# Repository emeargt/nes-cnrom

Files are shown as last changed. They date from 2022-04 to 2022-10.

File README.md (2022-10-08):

# nes-cnrom
[][cc-by-sa]

[cc-by-sa]: http://creativecommons.org/licenses/by-sa/4.0/
[cc-by-sa-shield]: https://img.shields.io/badge/License-CC%20BY--SA%204.0-lightgrey.svg

This repository contains a KiCad project for a NES-CN-ROM-256-05 cartridge pcb.

Original NES-CN-ROM-256-05 schematic is from N. Schenk's [NES repo](https://github.com/schenkzoola/NES/tree/main/Cartridges/NES/NES-CN-ROM-256-05). The schematic was modified to include currently available parts and their associated footprints.

The board matches the dimensions of the original and will idealy fit in standard or reproduction shells. A list of parts to populate the board can be found in the bom directory.

## Build Guide
There is a basic [build guide](./docs/buildguide.md) that provides some tips and resources for bringing up a board.

## Memory Support
v02 was designed to support the SST39SF0x0A series of 32 DIP flash chips. However, the AT27CxxxR series of 28 DIP EPROMs have a very similar pinout and should work on the board by mapping pin 1 of the EPROM to pin 3 of the 32 DIP footprint. Other 28 DIP memory chips may work as well, but their pinouts should be compared to that of the SST39SF0x0A to be certain.

## Schematic


## Board Layout
Top | Bottom
:---: | :---:
 | 

Board render (front):
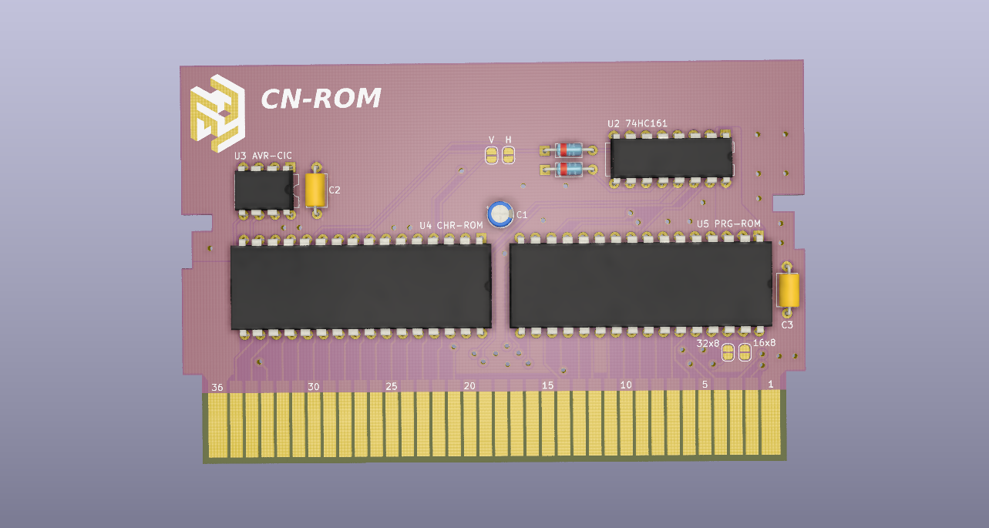
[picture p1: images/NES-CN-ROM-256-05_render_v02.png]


## Changelog

### [v02]
- New board layout to support 32 DIP flash chips (SST39SF0x0A)
- Add isometric logo design
- Increase board dimensions

### [v01.1]
- Connected pins 57 and 58 on the cartridge edge connector for internal VRAM enable.

### [v01]
- Initial schematic and board layout.

[v02]: https://github.com/emeargt/nes-cnrom/releases/tag/v02
[v01.1]: https://github.com/emeargt/nes-cnrom/releases/tag/v01.1
[v01]: https://github.com/emeargt/nes-cnrom/releases/tag/v01-alpha

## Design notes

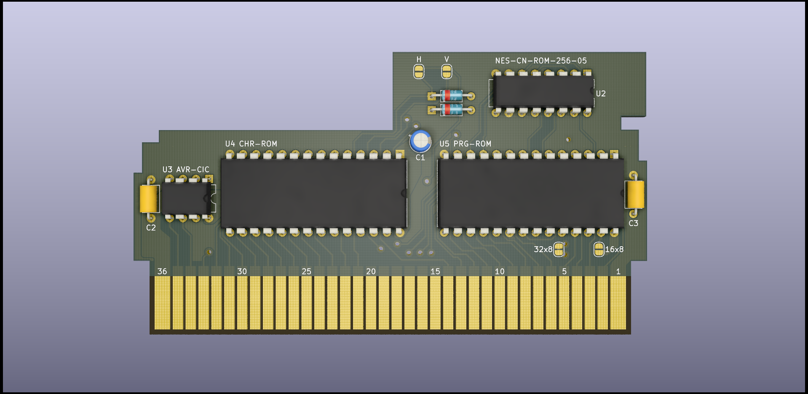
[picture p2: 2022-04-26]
images/NES-CN-ROM-256-05_render_v01.png

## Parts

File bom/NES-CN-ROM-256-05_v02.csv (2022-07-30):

Reference | Quantity | Value | Footprint | Notes | Datasheet
C1 | 1 | 22uF | Capacitor_THT:CP_Radial_D4.0mm_P1.50mm |  | https://www.digikey.ca/en/products/detail/panasonic-electronic-components/EEA-GA1A220/2504565
C2 C3 | 2 | 10nF | Capacitor_THT:C_Axial_L5.1mm_D3.1mm_P7.50mm_Horizontal |  | https://www.digikey.ca/en/products/detail/kemet/C410C103K5R5TA7200/818228
D1 D2 | 2 | 1N4148 | Diode_THT:D_DO-35_SOD27_P7.62mm_Horizontal | Do not populate (don't need to buy) | https://www.digikey.ca/en/products/detail/onsemi/1N4148TR/458811
U2 | 1 | 74HC161 | Package_DIP:DIP-16_W7.62mm |  | https://www.digikey.ca/en/products/detail/texas-instruments/SN74HC161N/376952
U3 | 1 | ATtiny13A-PU | Package_DIP:DIP-8_W7.62mm |  | https://www.digikey.ca/en/products/detail/microchip-technology/ATTINY13A-PU/1914671
U4 | 1 | CHR-ROM | Package_DIP:DIP-32_W15.24mm | Any SST39SF0x0A supported | https://www.digikey.ca/en/products/detail/microchip-technology/SST39SF010A-70-4C-PHE/2297826
U5 | 1 | PRG-ROM | Package_DIP:DIP-32_W15.24mm | Any SST39SF0x0A supported | https://www.digikey.ca/en/products/detail/microchip-technology/SST39SF010A-70-4C-PHE/2297826

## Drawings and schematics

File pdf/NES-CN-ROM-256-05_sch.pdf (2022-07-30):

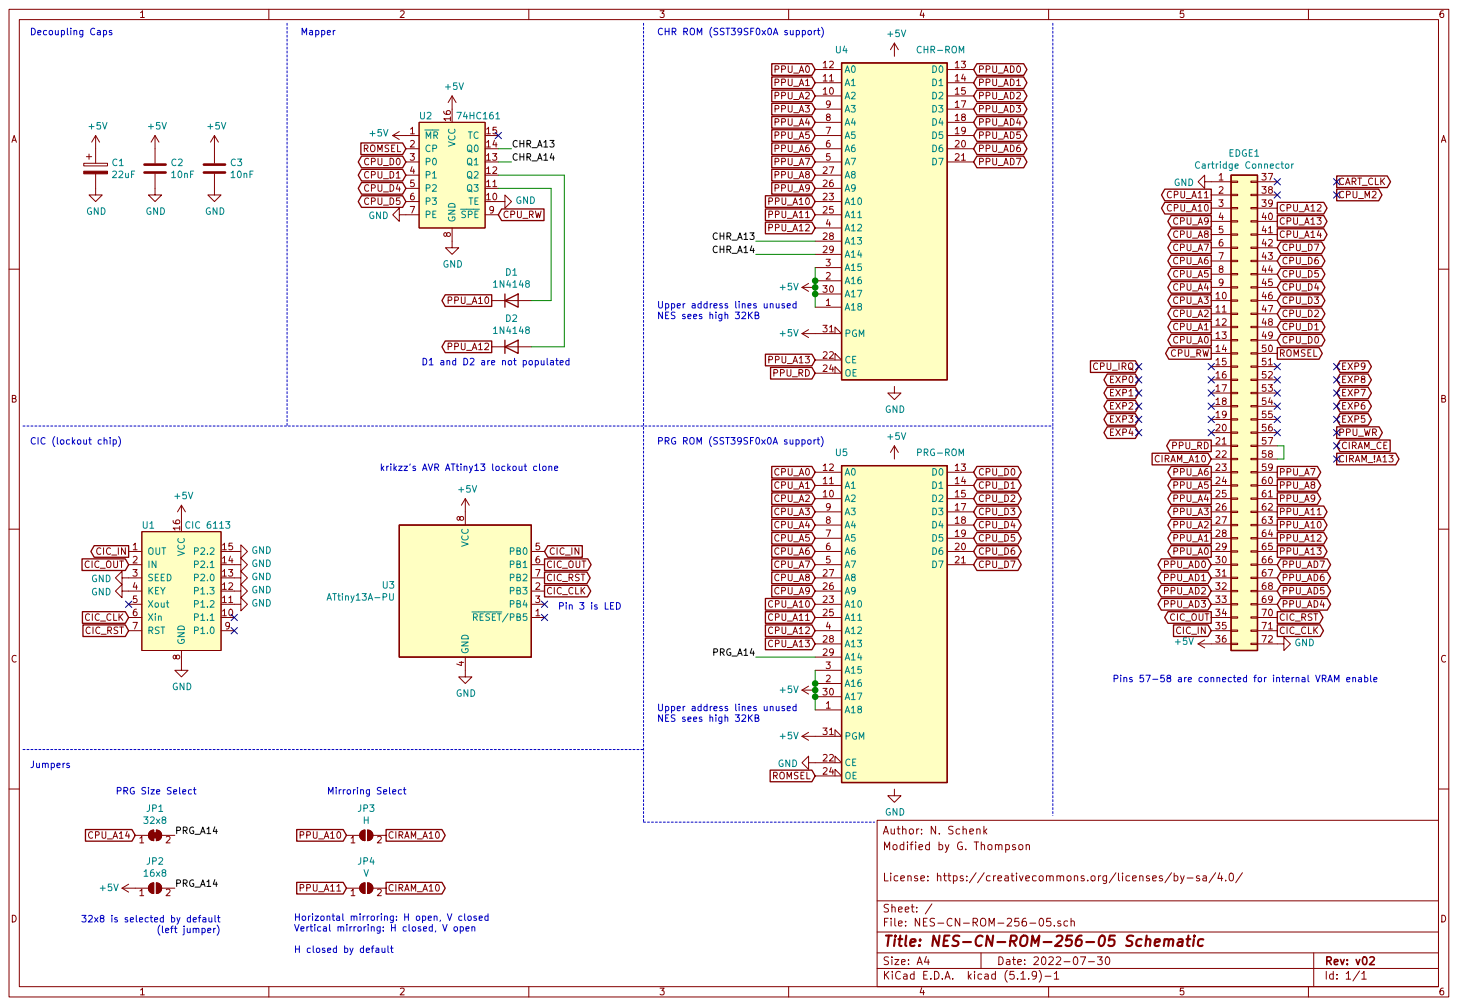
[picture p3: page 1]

8 P1.0 9 U1 CIC 6113 A18 1 A2 10 A1 11 A0 12 D0 13 D1 14 D2 15 D3 17 D4 18 D5 19 A16 2 D6 20 D7 21 CE 22 A10 23 OE 24 A11 25 A9 26 A8 27 A13 28 A14 29 A15 3 A17 30 PGM 31 A12 4 A7 5 A6 6 A5 7 A4 8 A3 9 U4 CHR-ROM

CHR_A13 Upper address lines unused

D1 and D2 are not populated

krikzz's AVR ATtiny13 lockout clone

Modified by G. Thompson Author: N. Schenk GND

Upper address lines unused
NES sees high 32KB

File: NES-CN-ROM-256-05.sch Sheet: / License: https://creativecommons.org/licenses/by-sa/4.0/

32x8 is selected by default

Horizontal mirroring: H open, V closed
Vertical mirroring: H closed, V open

Id: 1/1 Title: NES-CN-ROM-256-05 Schematic

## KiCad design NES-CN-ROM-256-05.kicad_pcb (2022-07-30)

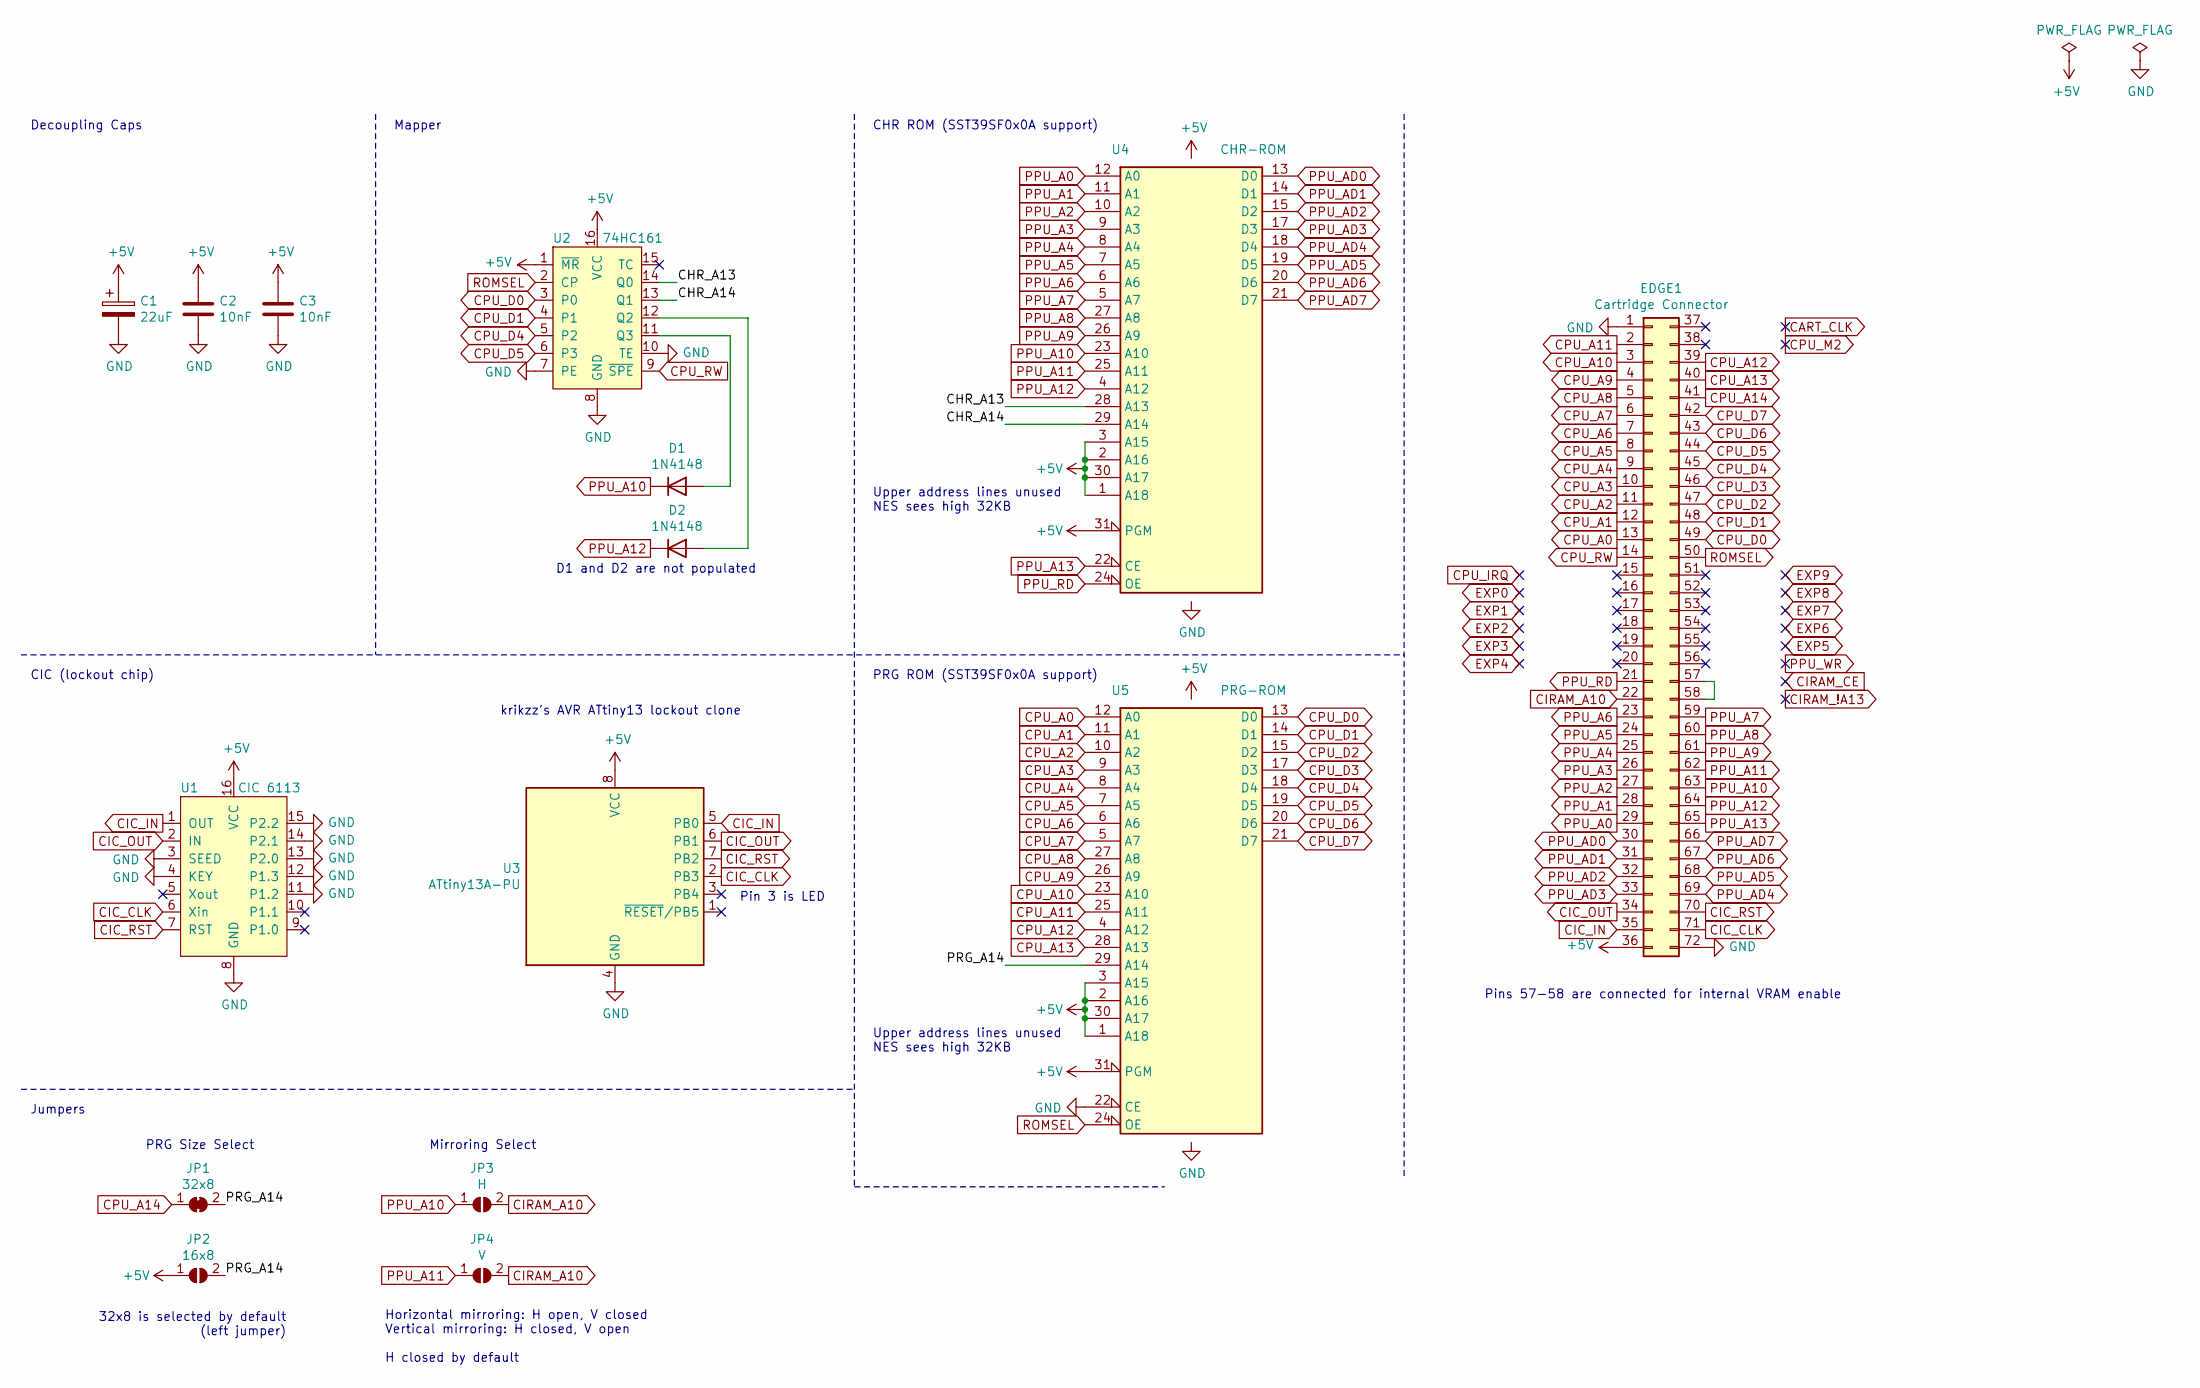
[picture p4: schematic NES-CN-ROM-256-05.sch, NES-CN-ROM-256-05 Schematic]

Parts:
C1: 22uF; CP_Radial_D4.0mm_P1.50mm
C2, C3: 10nF; C_Axial_L5.1mm_D3.1mm_P7.50mm_Horizontal
D1, D2: 1N4148; D_DO-35_SOD27_P7.62mm_Horizontal
EDGE1: Cartridge Connector; cartridge_edge_72
JP1: 32x8; SolderJumper-2_P1.3mm_Bridged_RoundedPad1.0x1.5mm
JP2: 16x8; SolderJumper-2_P1.3mm_Open_RoundedPad1.0x1.5mm
JP3: H; SolderJumper-2_P1.3mm_Open_RoundedPad1.0x1.5mm
JP4: V; SolderJumper-2_P1.3mm_Open_RoundedPad1.0x1.5mm
U1: CIC 6113; DIP-16_W7.62mm
U2: 74HC161; DIP-16_W7.62mm
U3: ATtiny13A-PU; DIP-8_W7.62mm
U4: CHR-ROM; DIP-32_W15.24mm
U5: PRG-ROM; DIP-32_W15.24mm

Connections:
+5V: C1.1, C2.1, C3.1, EDGE1.36, JP2.1 (A), U1.16 (VCC), U2.1 (~MR), U2.16 (VCC), U3.8 (VCC), U4.1 (A18), U4.2 (A16), U4.3 (A15), U4.30 (A17), U4.31 (PGM), U4.32 (VCC), U5.1 (A18), U5.2 (A16), U5.3 (A15), U5.30 (A17), U5.31 (PGM), U5.32 (VCC)
/CHR_A13: U2.14 (Q0), U4.28 (A13)
/CHR_A14: U2.13 (Q1), U4.29 (A14)
/PRG_A14: JP1.2 (B), JP2.2 (B), U5.29 (A14)
CIC_CLK: EDGE1.71, U1.6 (Xin), U3.2 (PB3)
CIC_IN: EDGE1.35, U1.1 (OUT), U3.5 (PB0)
CIC_OUT: EDGE1.34, U1.2 (IN), U3.6 (PB1)
CIC_RST: EDGE1.70, U1.7 (RST), U3.7 (PB2)
CIRAM_A10: EDGE1.22, JP3.2 (B), JP4.2 (B)
CPU_A0: EDGE1.13, U5.12 (A0)
CPU_A1: EDGE1.12, U5.11 (A1)
CPU_A2: EDGE1.11, U5.10 (A2)
CPU_A3: EDGE1.10, U5.9 (A3)
CPU_A4: EDGE1.9, U5.8 (A4)
CPU_A5: EDGE1.8, U5.7 (A5)
CPU_A6: EDGE1.7, U5.6 (A6)
CPU_A7: EDGE1.6, U5.5 (A7)
CPU_A8: EDGE1.5, U5.27 (A8)
CPU_A9: EDGE1.4, U5.26 (A9)
CPU_A10: EDGE1.3, U5.23 (A10)
CPU_A11: EDGE1.2, U5.25 (A11)
CPU_A12: EDGE1.39, U5.4 (A12)
CPU_A13: EDGE1.40, U5.28 (A13)
CPU_A14: EDGE1.41, JP1.1 (A)
CPU_D0: EDGE1.49, U2.3 (P0), U5.13 (D0)
CPU_D1: EDGE1.48, U2.4 (P1), U5.14 (D1)
CPU_D2: EDGE1.47, U5.15 (D2)
CPU_D3: EDGE1.46, U5.17 (D3)
CPU_D4: EDGE1.45, U2.5 (P2), U5.18 (D4)
CPU_D5: EDGE1.44, U2.6 (P3), U5.19 (D5)
CPU_D6: EDGE1.43, U5.20 (D6)
CPU_D7: EDGE1.42, U5.21 (D7)
CPU_RW: EDGE1.14, U2.9 (~SPE)
GND: C1.2, C2.2, C3.2, EDGE1.1, EDGE1.72, U1.3 (SEED), U1.4 (KEY), U1.8 (GND), U1.11 (P1.2), U1.12 (P1.3), U1.13 (P2.0), U1.14 (P2.1), U1.15 (P2.2), U2.7 (PE), U2.8 (GND), U2.10 (TE), U3.4 (GND), U4.16 (GND), U5.16 (GND), U5.22 (CE)
unnamed: D1.2 (A), U2.11 (Q3)
unnamed: D2.2 (A), U2.12 (Q2)
unnamed: EDGE1.57, EDGE1.58
PPU_A0: EDGE1.29, U4.12 (A0)
PPU_A1: EDGE1.28, U4.11 (A1)
PPU_A2: EDGE1.27, U4.10 (A2)
PPU_A3: EDGE1.26, U4.9 (A3)
PPU_A4: EDGE1.25, U4.8 (A4)
PPU_A5: EDGE1.24, U4.7 (A5)
PPU_A6: EDGE1.23, U4.6 (A6)
PPU_A7: EDGE1.59, U4.5 (A7)
PPU_A8: EDGE1.60, U4.27 (A8)
PPU_A9: EDGE1.61, U4.26 (A9)
PPU_A10: D1.1 (K), EDGE1.63, JP3.1 (A), U4.23 (A10)
PPU_A11: EDGE1.62, JP4.1 (A), U4.25 (A11)
PPU_A12: D2.1 (K), EDGE1.64, U4.4 (A12)
PPU_A13: EDGE1.65, U4.22 (CE)
PPU_AD0: EDGE1.30, U4.13 (D0)
PPU_AD1: EDGE1.31, U4.14 (D1)
PPU_AD2: EDGE1.32, U4.15 (D2)
PPU_AD3: EDGE1.33, U4.17 (D3)
PPU_AD4: EDGE1.69, U4.18 (D4)
PPU_AD5: EDGE1.68, U4.19 (D5)
PPU_AD6: EDGE1.67, U4.20 (D6)
PPU_AD7: EDGE1.66, U4.21 (D7)
PPU_RD: EDGE1.21, U4.24 (OE)
ROMSEL: EDGE1.50, U2.2 (CP), U5.24 (OE)

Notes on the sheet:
32x8 is selected by default (left jumper)
D1 and D2 are not populated
CHR ROM (SST39SF0x0A support)
PRG ROM (SST39SF0x0A support)
Mapper
Decoupling Caps
CIC (lockout chip)
Jumpers
krikzz's AVR ATtiny13 lockout clone
Mirroring Select
PRG Size Select
Pin 3 is LED
Horizontal mirroring: H open, V closed Vertical mirroring: H closed, V open H closed by default
Pins 57-58 are connected for internal VRAM enable
Upper address lines unused NES sees high 32KB

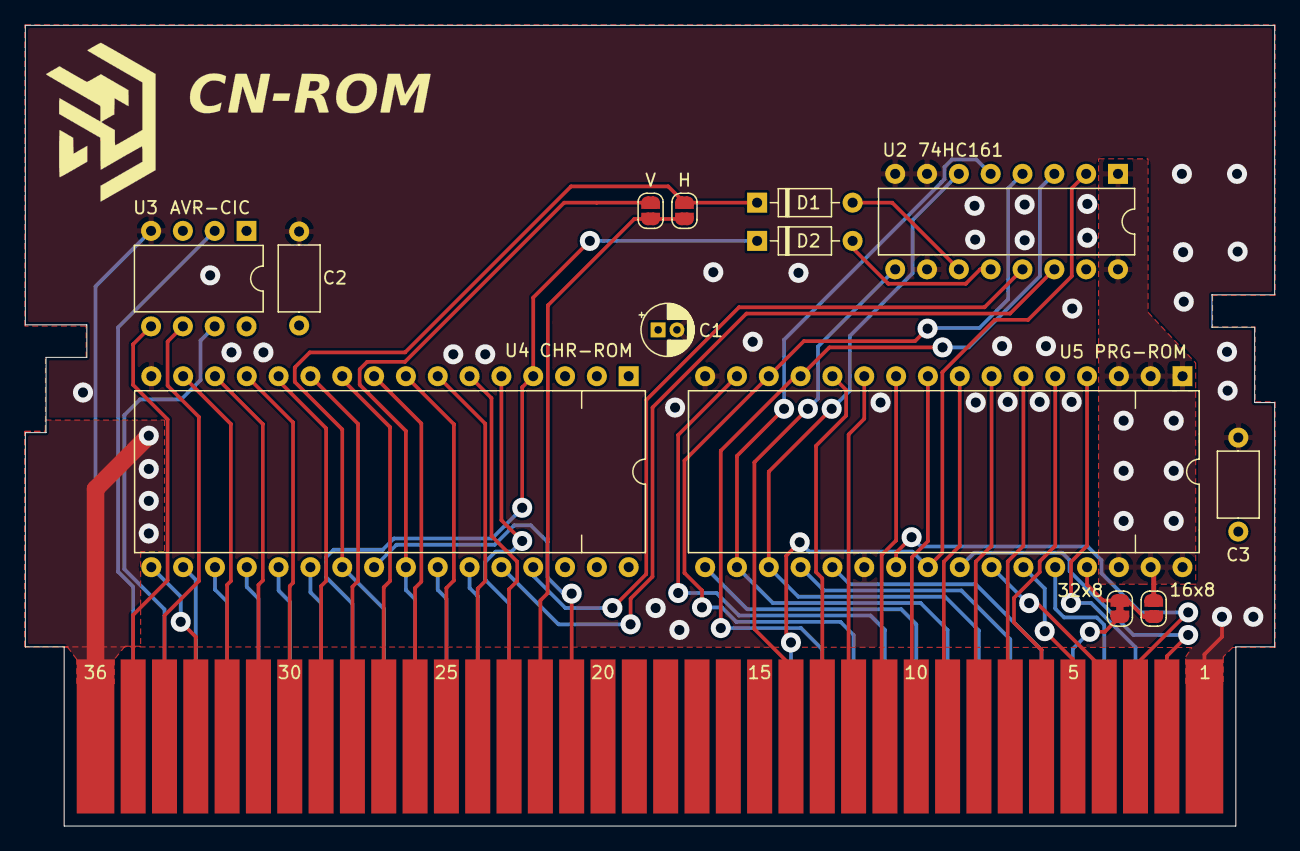
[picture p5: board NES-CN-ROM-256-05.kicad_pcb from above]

Board: 2 copper layers, 99.7 x 63.9 mm, 17 parts (0 on the bottom side), 61 nets.

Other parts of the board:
G1: LOGO; flash_logo
G2: LOGO; flash_negative_logo
G3: LOGO; cnrom_text

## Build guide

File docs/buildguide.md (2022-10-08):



# Build Guide

This document contains a loose build guide on how to order a board/parts, program the necessary chips, and populate the board.

**Contents**<br>
[Part Ordering](#part-ordering)<br>
[Programming ICs](#programming-ics)<br>
[Populating the board](#populating-the-board)<br>
[Additional Resources](#additional-resources)<br>

## Part Ordering

### PCB
The production files (gerbers) in this repository were generated according to JLCPCB specifications. Therefore, ordering a small quantity run of boards from JLCPCB will be used as an example for this guide. To fabricate boards at a different manufacturer, the gerbers should be regenerated from the KiCad project before ordering.

Grab the zip of gerbers from the [latest board release](https://github.com/emeargt/nes-cnrom/releases). Alternatively, you find the latest gerbers in the [gerber directory](../gerber/) at the git repo head. These are the production files you will need to provide JLCPCB to have the board manufactured.

Upload the gerber zip on the [JLCPCB website](https://jlcpcb.com/) and choose the following settings:<br>
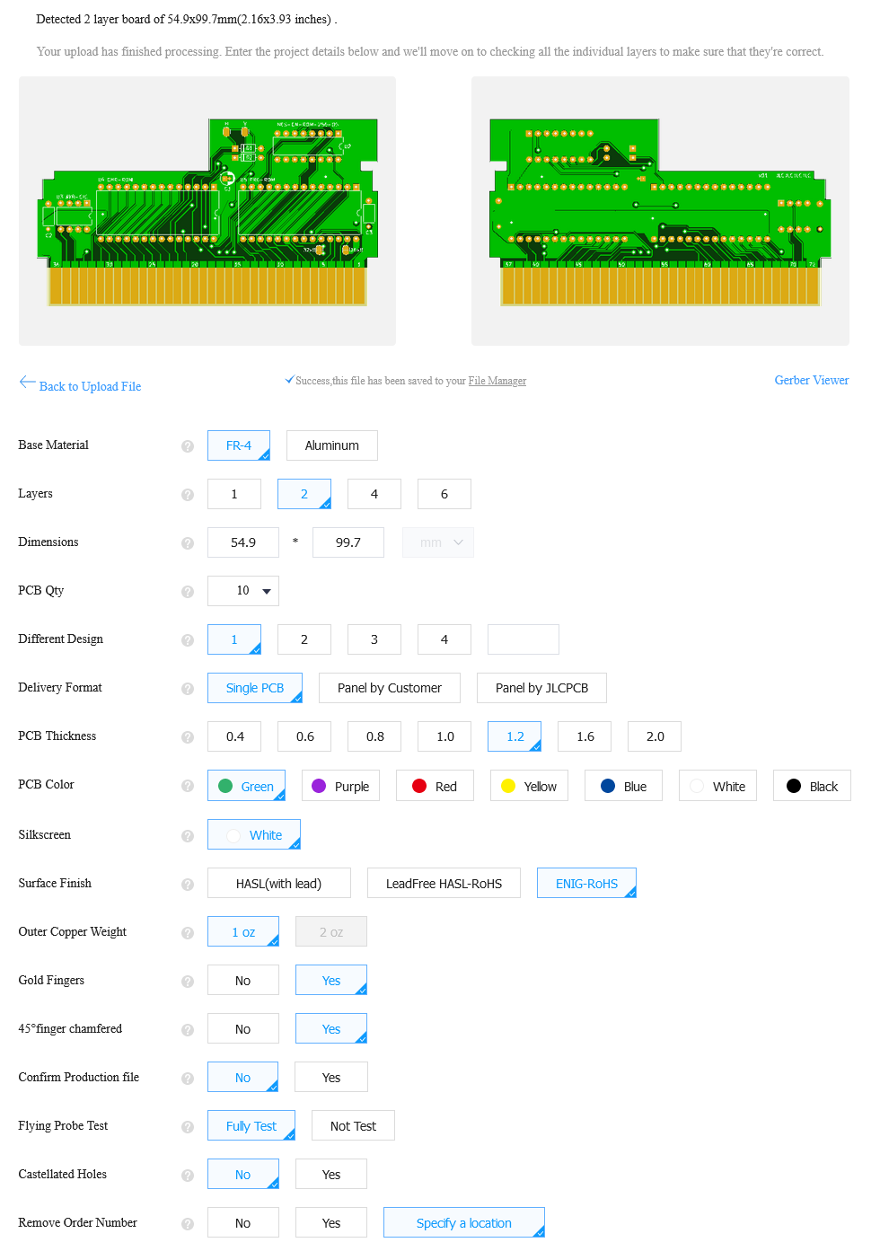
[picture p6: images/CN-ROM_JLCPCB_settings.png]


The important settings to note are
- *1.2mm thickness*: this is the thickness of original NES cartridge PCBs.
- *ENIG (Electroless Nickel Immersion Gold) surface finish*: ENIG offers a harder surface than the typical HASL finish. This is important for card edge connector durability after multiple insertion cycles in the NES. However, it is more expensive.
- *Gold fingers with 45 degree chamfer*: Gold fingers are necessary for the card edge connector and the 45 degree chamfer is better for inserting into the NES 72 pin connector.

You can adjust other settings to see how it affects the board cost/production time. Order the board when finished.

### Parts
A bill of materials (BOM) for the corresponding board version can be found in the [BOM directory](../bom/). The BOM contains the quantity of each part to buy and links to the [Digikey](https://www.digikey.ca) part page. The security diodes are typically not populated so you usually don't need to purchase those. Also, memory ICs can be selected based on part availability.

## Programming ICs

### AVR CIC
The board uses krikzz's multiregion CIC clone to handle the NES lockout. The clone uses an ATtiny13: an 8-bit AVR microcontroller. The firmware for the CIC clone can be found in [krikzz's avrciczz repo](https://github.com/krikzz/avrciczz).

You will need a programmer to upload the CIC firmware to the ATtiny13. I used an Arduino Uno setup as a in-circuit programmer with the [avrdude](https://github.com/avrdudes/avrdude/) command line utility to upload firmware. [This guide](https://docs.arduino.cc/built-in-examples/arduino-isp/ArduinoISP) is useful for setting up an Arduino as a programmer. Another option is the TL866II universal programmer; it's more expensive than an Arduino, but requires less setup. 

The important thing to note when programming the AVR CIC is that the fuse bits are set correctly (so the ATtiny13 can be clocked by the NES, necessary for timing). krikzz's repo notes that the .elf already contains the fuse setting; however, when uploading this file with avrdude and then reading back the fuse bit values I found that they didn't match the expected values of 0xFB (for high fuse bits) and 0x70 (for low fuse bits). I used this avdude command to upload the .elf and manually set the fuse bits:

```bash
avrdude -p t13a -c avrisp -P <port> -b 19200 -U flash:w:avrciczz.elf:e -U hfuse:w:0xfb:m -U lfuse:w:0x70:m
```

Replace `<port>` with whatever serial port your programmer is connected to (COM on Windows, ttyS on Linux).

Regardless of what programmer/utility you use to upload the firmware, I would read back the fuse bits and check they match the expected values before the soldering the chip to the board.

### CHR and PRG ROMs
The game image you are trying to put on a board needs to be split into two halves, a CHR ROM (graphics data) and PRG ROM (game code), so it can be programmed to two flash memory ICs. [famiROM](https://www.angelfire.com/retro/kingmercury/) is a useful Windows program for splitting a game image into its CHR ROM and PRG ROM files. Make sure that both CHR and PRG files are expanded to fill the memory size of the flash ICs you are using; this can be done in famiROM by selecting the appropriate target EPROM size. See the how to make an NES Cartridge guide by Bucket Mouse in [Additional Resources](#additional-resources) for more info on famiROM and other tools you can use for splitting game images.

> **It's important that the CHR and PRG ROMs are expanded to fill the memory size as the board ties the flash ICs upper address lines high meaning only the upper 32KB of is accessed by the NES. If you were to only program 32KB of data to the flash IC (instead of filling it with duplicated 32KB chunks), it would be stored in the lower memory addresses and the NES wouldn't be able to access it.**

Now with the game separated into CHR and PRG files, they need to be programmed to the flash ICs. I followed a tutorial by slu4coder to create a flash programmer on a breadboard with an Arduino Nano and use a custom Windows-based command line utility to write data to a flash IC. You can find a tutorial video and code in the [SST39SF010-FLASH-Programmer](https://github.com/slu4coder/SST39SF010-FLASH-Programmer) repository. The less time consuming method would be to use a universal programmer such as the TL866II.

## Populating the board
Get out your soldering iron and favourite solder, then populate the board!

The order of operations I prefer is
1) Ceramic capacitors (C2, C3)
2) Mirroring jumper (H or V)
3) ICs (ROMs, CIC, counter)
4) Electrolytic capacitor (C1)

## Additional Resources

[How to make an NES Cartridge](https://mousebitelabs.com/2017/06/25/how-to-make-an-nes-reproduction-cartridge/) guide by Bucket Mouse.

---

[Home](buildguide.md#top)

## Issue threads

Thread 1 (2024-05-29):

Horizontal and Vertical is swapped

brunhuber, 2024-05-29:
After writing several games , it seems that the V and H markings are swapped.

emeargt, 2024-06-18:
Hey, thanks for flagging this. I seem to recall the nametable mirroring terminology nintendo used on the original boards being unnecessarily confusing. The V and H markings on the board select the nametable arrangement, not the type of mirroring directly. For a vertical arrangement of the nametable, horizontal mirroring is used so the "V" jumper is shorted (for vertical arrangement). The "H" jumper is shorted for a horizontal arrangement of the nametable and vertical mirroring. This seems counterintuitive, as for horizontal mirroring you would expect to short the "H" jumper, but that's how nintendo decided to do it and I wanted to keep this project consistent with the original boards. If you haven't come across this page already, here's some more info on [mirroring](https://www.nesdev.org/wiki/Mirroring).

I put a note in the schematic under the mirroring select symbols:
> Horizontal mirroring: H open, V closed
> Vertical mirroring: H closed, V open

Let me know if this lines up with how the nametables are arranged in your games. I might need to update the build guide to point this out.

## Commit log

2022-04-26 [1] Change gerbers to protel file ext [2] Fix board dimensions [3] Add screenshot of jlcpcb order settings
    [NES-CN-ROM-256-05-B_Cu.gbl, NES-CN-ROM-256-05-B_Mask.gbs, NES-CN-ROM-256-05-B_Paste.gbp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]
2022-04-28 Add schematic attribution to readme
2022-06-10 [1] Connect cartridge pins 57-58 for NES internal VRAM enable line. [2] Regenerate gerbers.
    [NES-CN-ROM-256-05-B_Cu.gbl, NES-CN-ROM-256-05-B_Mask.gbs, NES-CN-ROM-256-05-B_Paste.gbp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]
2022-07-30 New board layout to support 32 dip flash chips
    [NES-CN-ROM-256-05-B_Cu.gbl, NES-CN-ROM-256-05-B_Mask.gbs, NES-CN-ROM-256-05-B_Paste.gbp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]
2022-07-31 Add board dimension increase note to changelog

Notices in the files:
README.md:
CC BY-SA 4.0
